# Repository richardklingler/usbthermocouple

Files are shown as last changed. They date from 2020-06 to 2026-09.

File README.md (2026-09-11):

# 2-channel USB thermocouple sensor

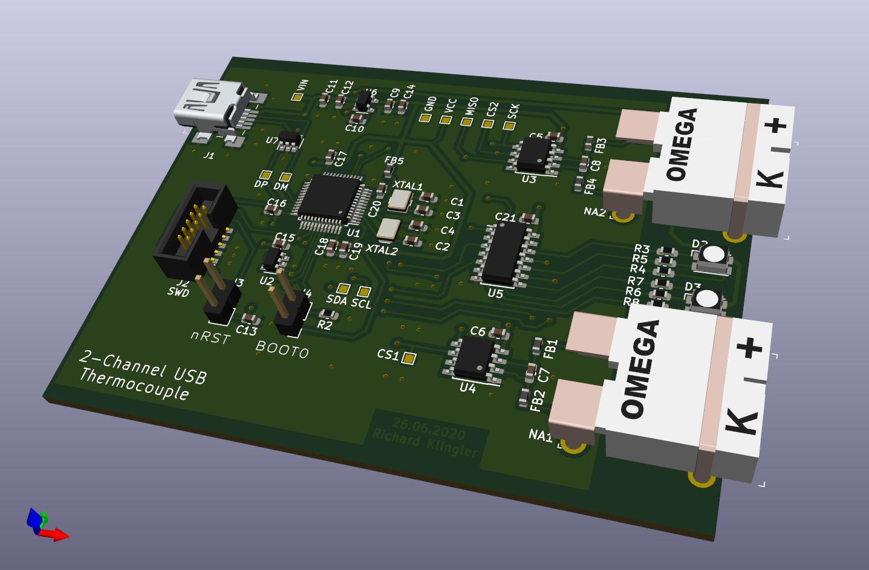
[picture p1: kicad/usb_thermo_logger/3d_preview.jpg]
USB Thermocouple Sensor


### Introduction

This is my first ever published project on Github, so most probably not error free (o;

It is a small 60mm x 80mm USB device which reads out temperatures from two K-type thermocouple sensors via MAX31855 converters.
As the main controller a STM32F070CBT6 was chosen due to the simplicity in setting up the STM32CubeIDE and configure it for USB CDC mode.

[**STM32CubeIDE**](https://www.st.com/en/development-tools/stm32cubeide.html)

For schematic and PCB design the great KiCAD software was used:

[**KiCAD**](https://www.kicad.org/)

### Repository layout

| Folder | Content |
|---|---|
| `kicad/usb_thermo_logger` | Schematic, PCB layout, 3D preview, datasheets |
| `openscad` | Front and back panels for the enclosure (`.scad` and `.stl`) |
| `stm32/USB_Thermologger_2` | Firmware, STM32CubeIDE project |
| `python` | PyQt5 logger application for the **previous** firmware (see below) |

### How it works

The device is powered from the USB port and registers as a USB CDC serial interface, so no driver is needed:

| OS | Device |
|---|---|
| Linux | `/dev/ttyACM0` |
| macOS | `/dev/cu.usbmodem…` |
| Windows | `COMx` |

The baud rate setting doesn't matter.

| USB descriptor | Value |
|---|---|
| Vendor ID / Product ID | `0x1209` / `0x5304` ([pid.codes](https://pid.codes/1209/5304/)) |
| Manufacturer | Klingler Engineering |
| Product | USB Thermocouple Logger |
| Serial number | Unique per device, derived from the STM32 chip ID |

The device doesn't send anything on its own. The host software asks for a measurement whenever it wants one, and adds its own timestamps.
This keeps the firmware simple: no clock to set, no drift, and the polling interval is completely up to the host.

The MAX31855 converts about 10 times per second, so polling faster than every 100 ms just returns the same value again.

### USB commands

| Command | Reply | Function |
|---|---|---|
| `?` | `24.50,23.75` | Read all channels |
| `*IDN?` | `Klingler Engineering,TC2,208438763130,1.0.0` | Identify the device |
| `C?` | `2` | Number of channels |
| `X1704` | none | Enter the DFU bootloader (see [Firmware update](#firmware-update)) |

Every reply is one line terminated by CR LF (`\r\n`).

Commands don't need a line ending, but **each command has to arrive in one piece**. The firmware looks at every USB packet on its own, so send the whole command with a single write.
A terminal program like `screen` sends every keystroke separately, which only works for the single-character `?`.

Send one command and wait for its reply before sending the next one.

### Identification

`*IDN?` follows the usual convention of measurement instruments and returns four comma-separated fields:

| Field | Example | Meaning |
|---|---|---|
| 1 | `Klingler Engineering` | Manufacturer |
| 2 | `TC2` | Model |
| 3 | `208438763130` | Serial number, identical to the USB serial number |
| 4 | `1.0.0` | Firmware version |

`C?` returns the number of thermocouple channels. Host software should use it instead of assuming a fixed number, so it also works with devices that have more channels.

### Reply format

After a `?`, the device replies with one line containing one value per channel, separated by commas. On the 2-channel device:

| Reply | Meaning |
|---|---|
| `24.50,23.75` | Both channels have a thermocouple |
| `24.50,-` | Only channel 1 has a valid reading |
| `-,23.75` | Only channel 2 has a valid reading |
| `-,-` | No valid reading on either channel |

Values are in degrees Celsius with a resolution of 0.25 °C. Negative temperatures are reported as negative values, e.g. `-12.25`.
The MAX31855 reports -270 °C to +1800 °C; the usable range of a K-type thermocouple itself is roughly -200 °C to +1350 °C.

### Errors

A `-` is sent for a channel when the MAX31855 reports a fault:

- thermocouple not connected (open circuit)
- thermocouple shorted to GND
- thermocouple shorted to VCC

### Quick test

With `screen` on Linux or macOS, type `?` and the reply appears (exit with Ctrl-A, then K):

```
screen /dev/ttyACM0 115200
```

For the other commands, use Python and [pyserial](https://pypi.org/project/pyserial/), which sends each command in one write:

```python
import serial

with serial.Serial('/dev/ttyACM0', timeout=1) as port:   # macOS: /dev/cu.usbmodem..., Windows: COM3
    for command in (b'*IDN?', b'C?', b'?'):
        port.write(command)
        print(command.decode(), '->', port.readline().decode().strip())
```

A simple logger that polls once per second and adds host timestamps:

```python
import serial, time
from datetime import datetime

with serial.Serial('/dev/ttyACM0', timeout=1) as port:
    while True:
        port.reset_input_buffer()
        port.write(b'?')
        reply = port.readline().decode(errors='replace').strip()
        print(f"{datetime.now().isoformat(timespec='milliseconds')},{reply}")
        time.sleep(1)
```

### Building the firmware

1. In STM32CubeIDE, use *File → Import → Existing Projects into Workspace* and select `stm32/USB_Thermologger_2`.
2. Build the *Release* configuration.
3. To get a `.bin` file for DFU flashing, enable *Project → Properties → C/C++ Build → Settings → MCU Post build outputs → Convert to binary file*.

### Firmware update

The device can be put into the STM32 DFU bootloader by sending a command, so no BOOT0 jumper or programmer is needed:

```
printf 'X1704' > /dev/ttyACM0
```

The device then re-enumerates as *STM32 BOOTLOADER* (`0483:df11`). Flash the new firmware with [dfu-util](https://dfu-util.sourceforge.net/), which is also available via Homebrew on macOS:

```
dfu-util -a 0 -s 0x08000000:leave -D stm32/USB_Thermologger_2/Release/USB_Thermologger_2.bin
```

Alternatively the firmware can be flashed directly from STM32CubeIDE with an ST-LINK via SWD.

### Changes

**September 2026**

- Project updated for current STM32CubeIDE versions and toolchains.
- The device no longer sends measurements continuously. It only replies to `?`.
- Removed the RTC time (`T`), date (`D`) and interval (`I`) commands, and the planned offset command (`O`). Timestamps, interval and calibration offsets are now the job of the host software.
- New commands `*IDN?` (identification) and `C?` (channel count).
- The device now uses its own USB ID `1209:5304` and reports as *USB Thermocouple Logger* by *Klingler Engineering*, instead of ST's generic `0483:5740`.
- Sensor faults are detected via the MAX31855 fault bit.
- Fixed negative temperatures, which were previously reported as values above 2000 °C.
- Reply lines now end with `\r\n` instead of `\n\r`.

The PyQt5 application in `python/` was written for the previous firmware (continuous output, RTC commands) and doesn't work with the current firmware.

### License

Firmware and software: GPL-3.0, see [LICENSE](LICENSE).
Hardware: CERN Open Hardware Licence v1.2, see [OSH_License.txt](OSH_License.txt).

### Donations

All my projects (currently not much but growing ;o) are self financed. If you like you can make a donation to my Paypal.me link:

paypal.me/renderingfun
[**Paypal Me Link**](https://paypal.me/renderingfun)

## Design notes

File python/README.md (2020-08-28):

### Sample Python Qt5 USB Thermo logger application

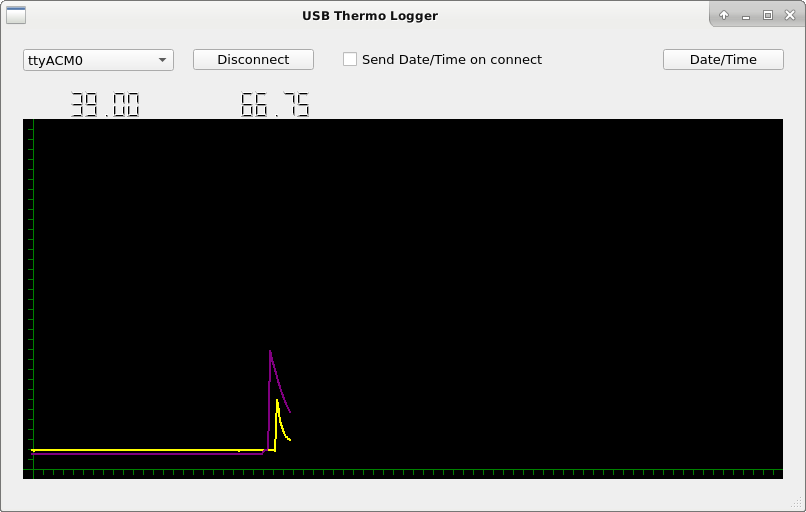
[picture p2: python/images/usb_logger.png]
PyQt5 USB logger


This is a simple PyQt5 application for rendering the returned temperature data from my USB thermocouple converter.

The main window layout is done in Qt 5 designer and can be converted to the modules/MainWindow.py file with:

    pyuic5 designer/main.ui -o modules/MainWindow.py

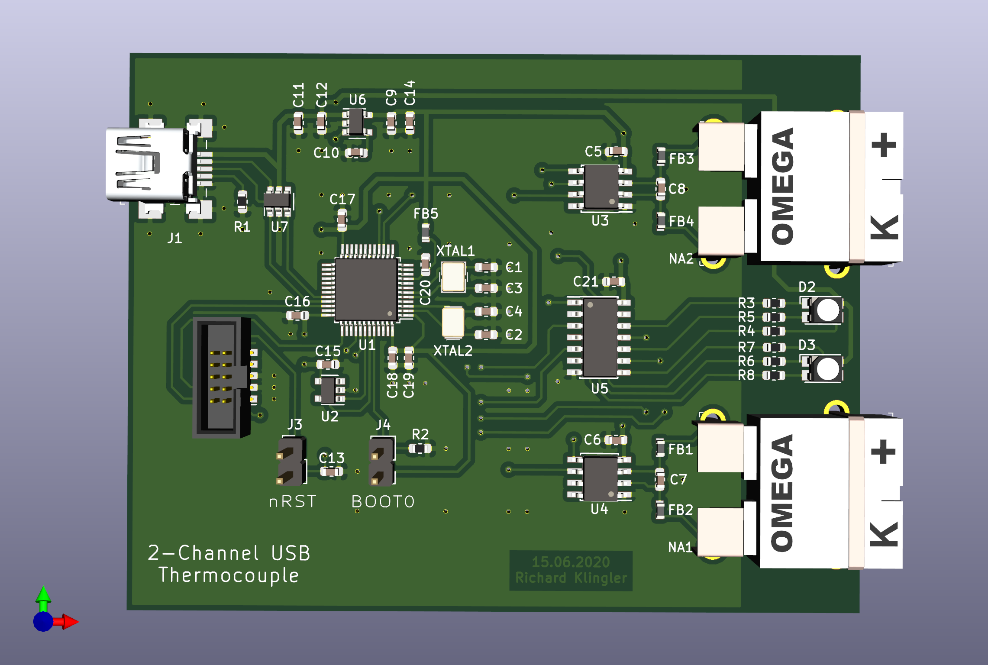
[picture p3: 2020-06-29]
kicad/usb_thermo_logger/3d_preview.png

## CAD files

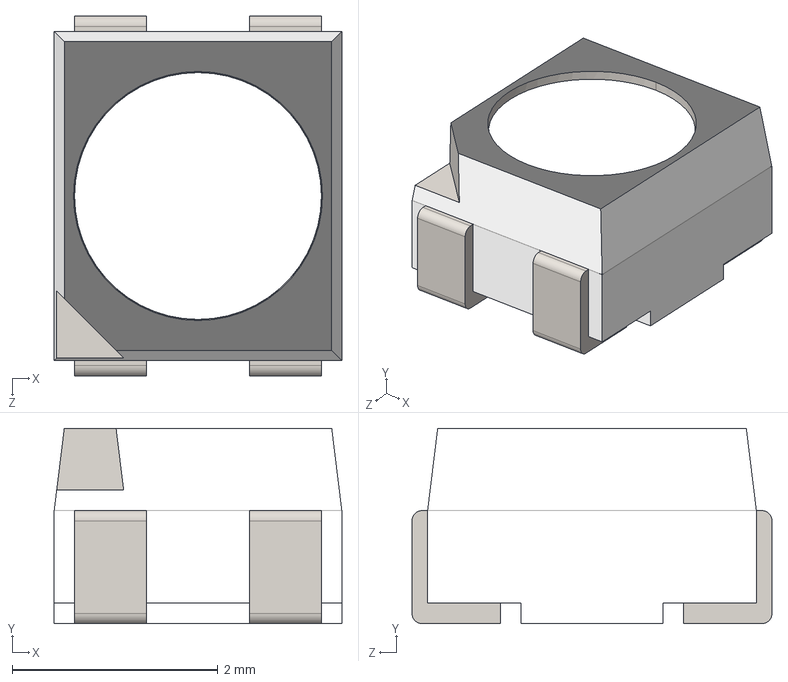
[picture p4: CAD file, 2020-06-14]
kicad/usb_thermo_logger/3d/ASMB-MTB0-0A3A2.STEP
2.80 x 1.90 x 3.50 mm

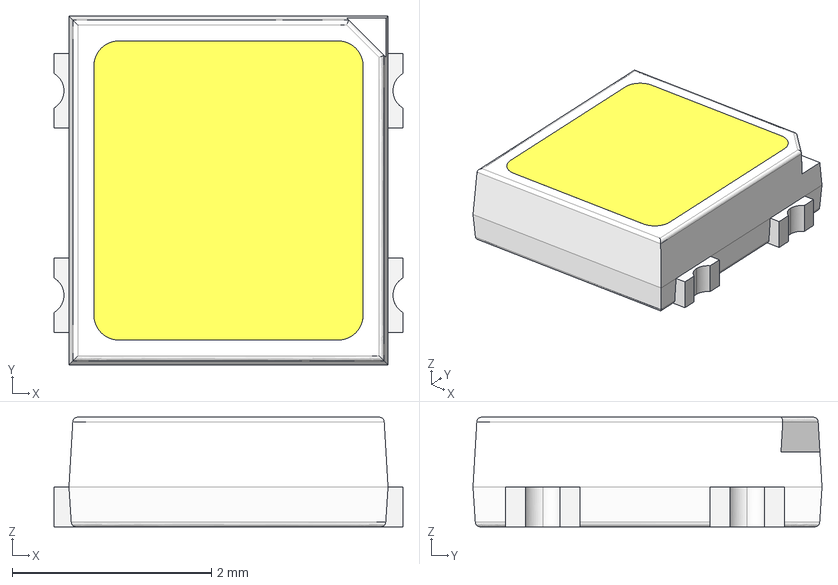
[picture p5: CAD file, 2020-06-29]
kicad/usb_thermo_logger/3d/PLCC4.stp
3.50 x 3.50 x 1.10 mm

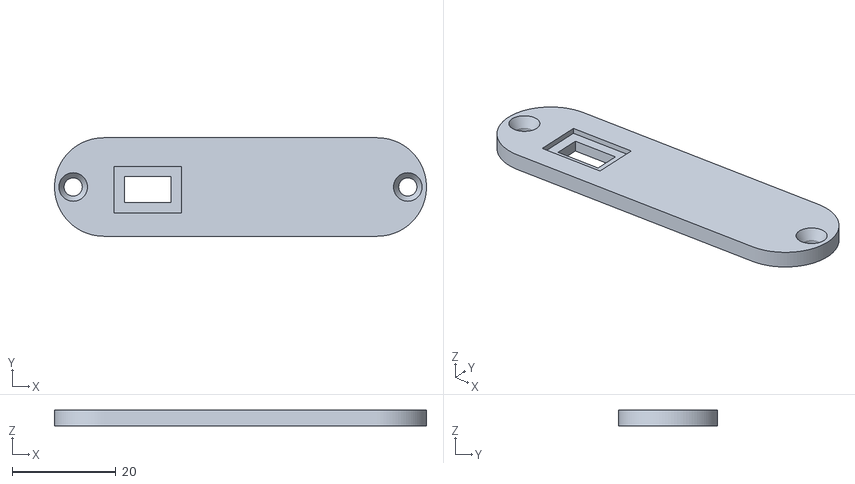
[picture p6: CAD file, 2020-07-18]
openscad/panel_back.stl
71.7 x 19.0 x 3.00

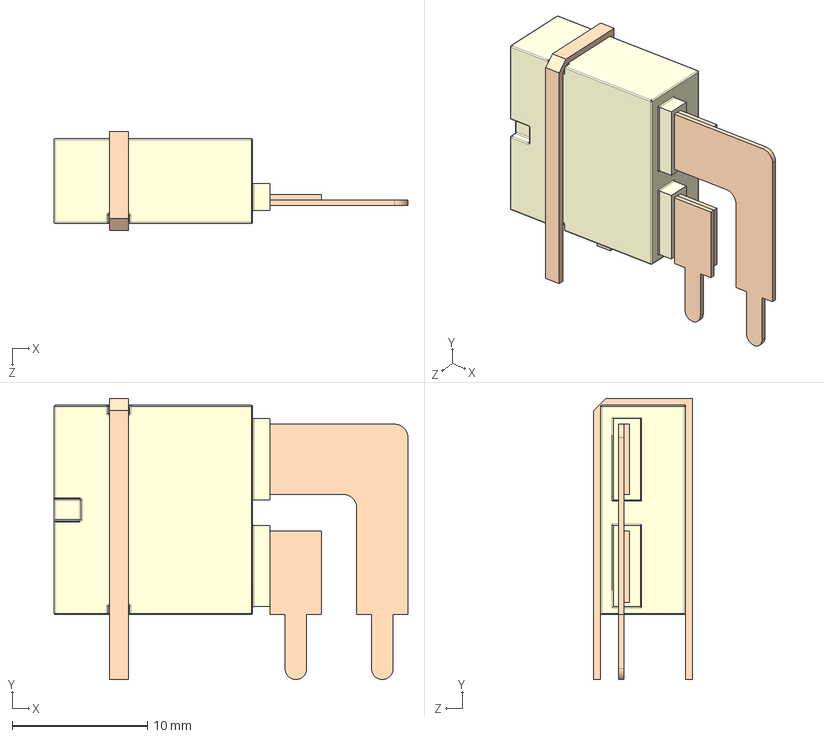
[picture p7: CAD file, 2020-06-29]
kicad/usb_thermo_logger/3d/PCC-SMP-V-K--3DModel-STEP-56544.STEP
26.2 x 20.8 x 7.30 mm

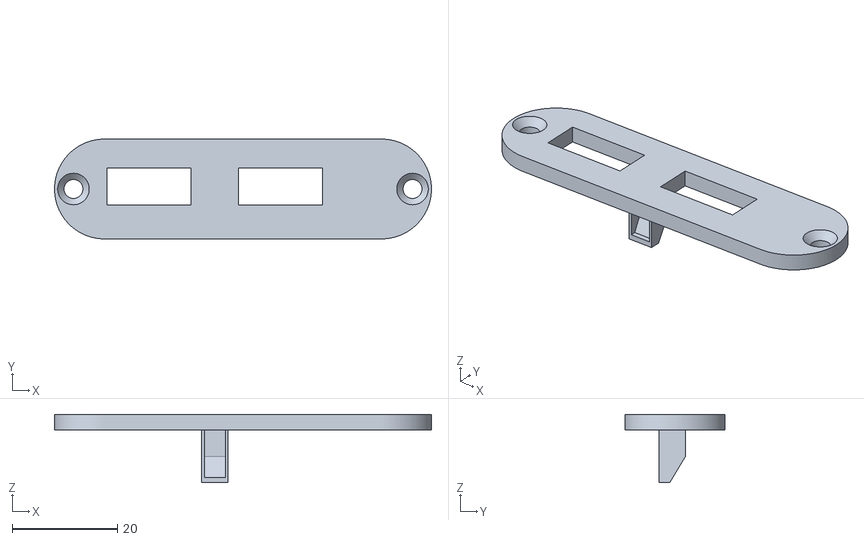
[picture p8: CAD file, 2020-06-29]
openscad/panel_front.stl
71.7 x 19.0 x 13.0

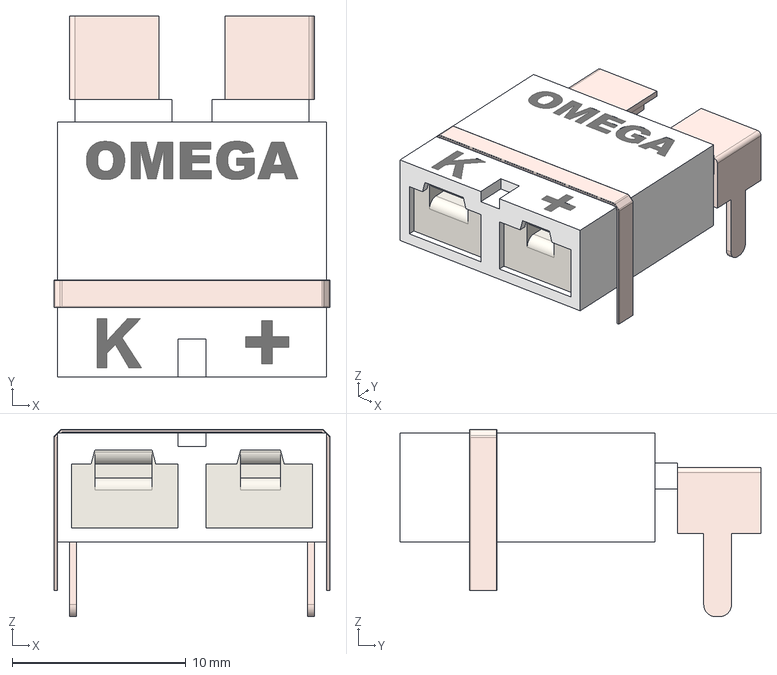
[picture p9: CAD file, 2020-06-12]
kicad/usb_thermo_logger/3d/PCC-SMP-K.step
15.9 x 20.8 x 10.8 mm

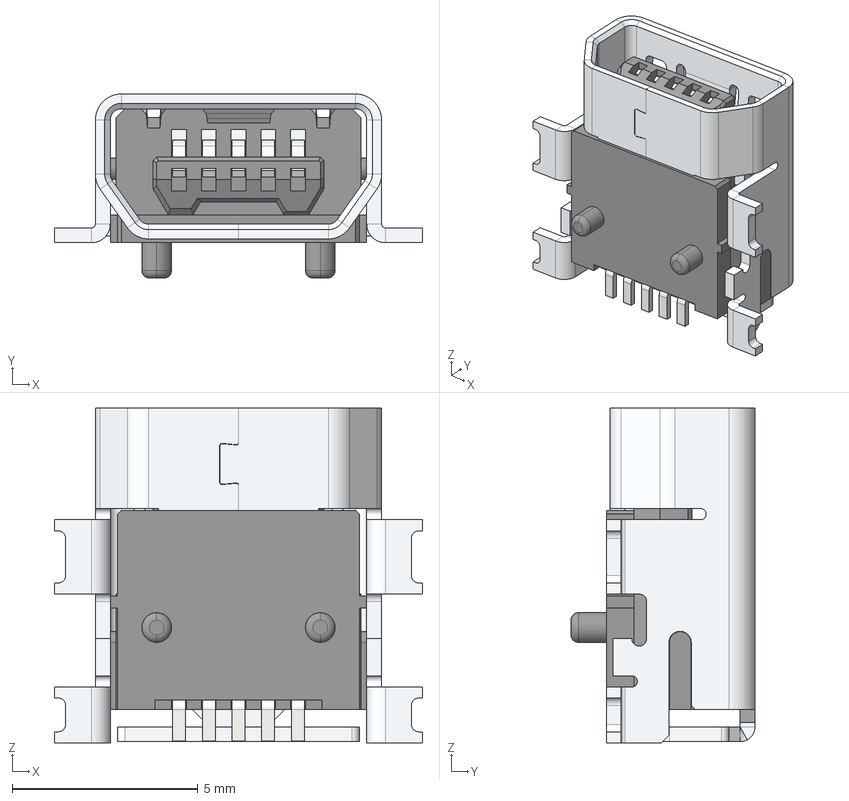
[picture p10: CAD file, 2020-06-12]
kicad/usb_thermo_logger/3d/MOLEX_0678038020.step
9.90 x 4.95 x 9.00 mm

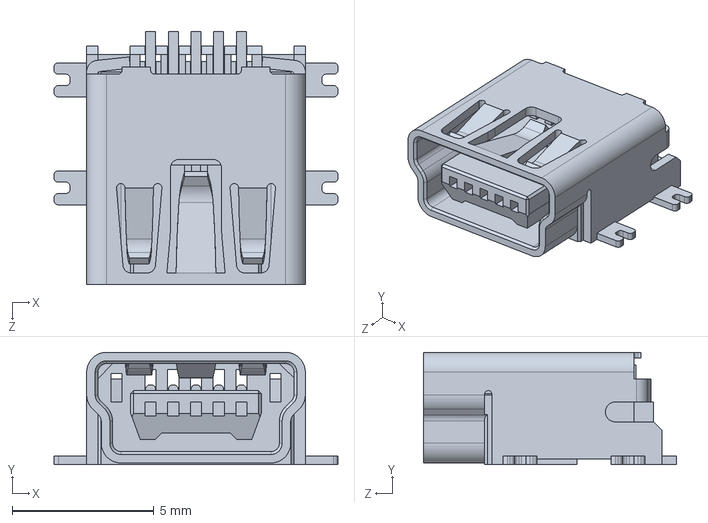
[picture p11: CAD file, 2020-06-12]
kicad/usb_thermo_logger/3d/USB_Mini_B_SMD_buchse.step
10.0 x 3.96 x 8.90 mm

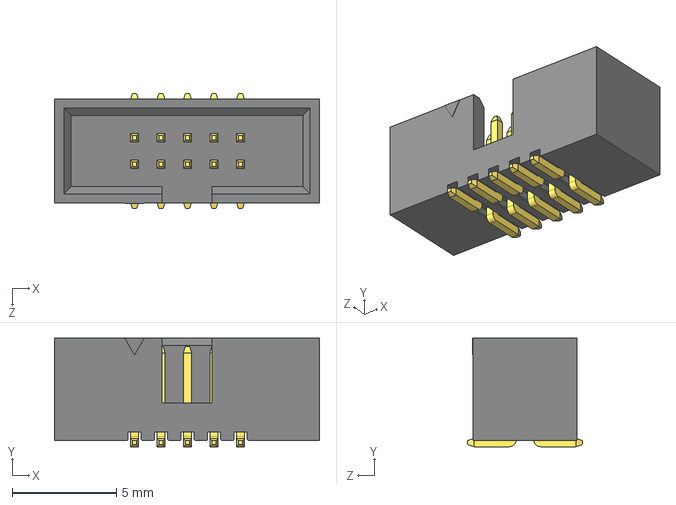
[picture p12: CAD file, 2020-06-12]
kicad/usb_thermo_logger/3d/3220-10-0300-00 3D.step
12.7 x 5.20 x 5.50 mm
801-2195SM-10
802-2195SM x 10

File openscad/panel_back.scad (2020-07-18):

$fn = 100;

// Edge radius of the hammond 1455B802 case
$r = 9.5;

// Width
$w = 71.74;

// Thickness
$t = 3;

// Distance of screw holes
$d = 64.53;
// Screw radius
$sr = 3.5 / 2;

// Height of PCB top
$ph = 6.5;
// K connector dimension (w x h
$cw = 9;
$ch = 5;

difference()
{
    union()
    {
        // Whole front element
        hull()
        {
            translate([$r, $r, 0]) cylinder($t, $r, $r);
            translate([$w - $r, $r, 0]) cylinder($t, $r, $r);
        }
    }
    // Screw holes
    translate([($w / 2) - ($d / 2), $r, -1]) cylinder($t + 2, $sr, $sr);
    translate([($w / 2) + ($d / 2), $r, -1]) cylinder($t + 2, $sr, $sr);
    translate([($w / 2) - ($d / 2), $r, $t - 2]) cylinder(2.1, $sr, 2.8);
    translate([($w / 2) + ($d / 2), $r, $t - 2]) cylinder(2.1, $sr, 2.8);

    // Connector cutouts
    translate([13.5, $ph, -1]) cube([$cw, $ch, $t + 2], false);
    translate([13.5 - 2, $ph - 2, 2]) cube([$cw + 4, $ch + 4, $t + 2], false);
}

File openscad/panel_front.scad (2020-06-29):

$fn = 100;

// Edge radius of the hammond 1455B802 case
$r = 9.5;

// Width
$w = 71.74;

// Thickness
$t = 3;

// Distance of screw holes
$d = 64.53;
// Screw radius
$sr = 3.6 / 2;

// Height of PCB top
$ph = 6.5;
// K connector dimension (w x h
$cw = 16;
$ch = 7;

difference()
{
    union()
    {
        // Whole front element
        hull()
        {
            translate([$r, $r, 0]) cylinder($t, $r, $r);
            translate([$w - $r, $r, 0]) cylinder($t, $r, $r);
        }
        // LED
        hull()
        {
            translate([28, $ph, -5]) cube([5, 5, 5], false);
            translate([28, $ph, -10]) cube([5, 2, 5], false);
        }
    }
//    translate([28.5, $ph - 1, -8]) cube([4, 4, 10], false);
    hull()
    {
        translate([28.5, $ph - 1, -5]) cube([4, 4, 5], false);
        translate([28.5, $ph - 1, -9]) cube([4, 2, 5], false);
    }
    
    // Screw holes
    translate([($w / 2) - ($d / 2), $r, -1]) cylinder($t + 2, $sr, $sr);
    translate([($w / 2) + ($d / 2), $r, -1]) cylinder($t + 2, $sr, $sr);
    translate([($w / 2) - ($d / 2), $r, $t - 1.5]) cylinder($t + 2, $sr, $sr + 4);
    translate([($w / 2) + ($d / 2), $r, $t -1.5]) cylinder($t + 2, $sr, $sr + 4);

    // Connector cutouts
    translate([10, $ph, -1]) cube([$cw, $ch, $t + 2], false);
    translate([35, $ph, -1]) cube([$cw, $ch, $t + 2], false);
}

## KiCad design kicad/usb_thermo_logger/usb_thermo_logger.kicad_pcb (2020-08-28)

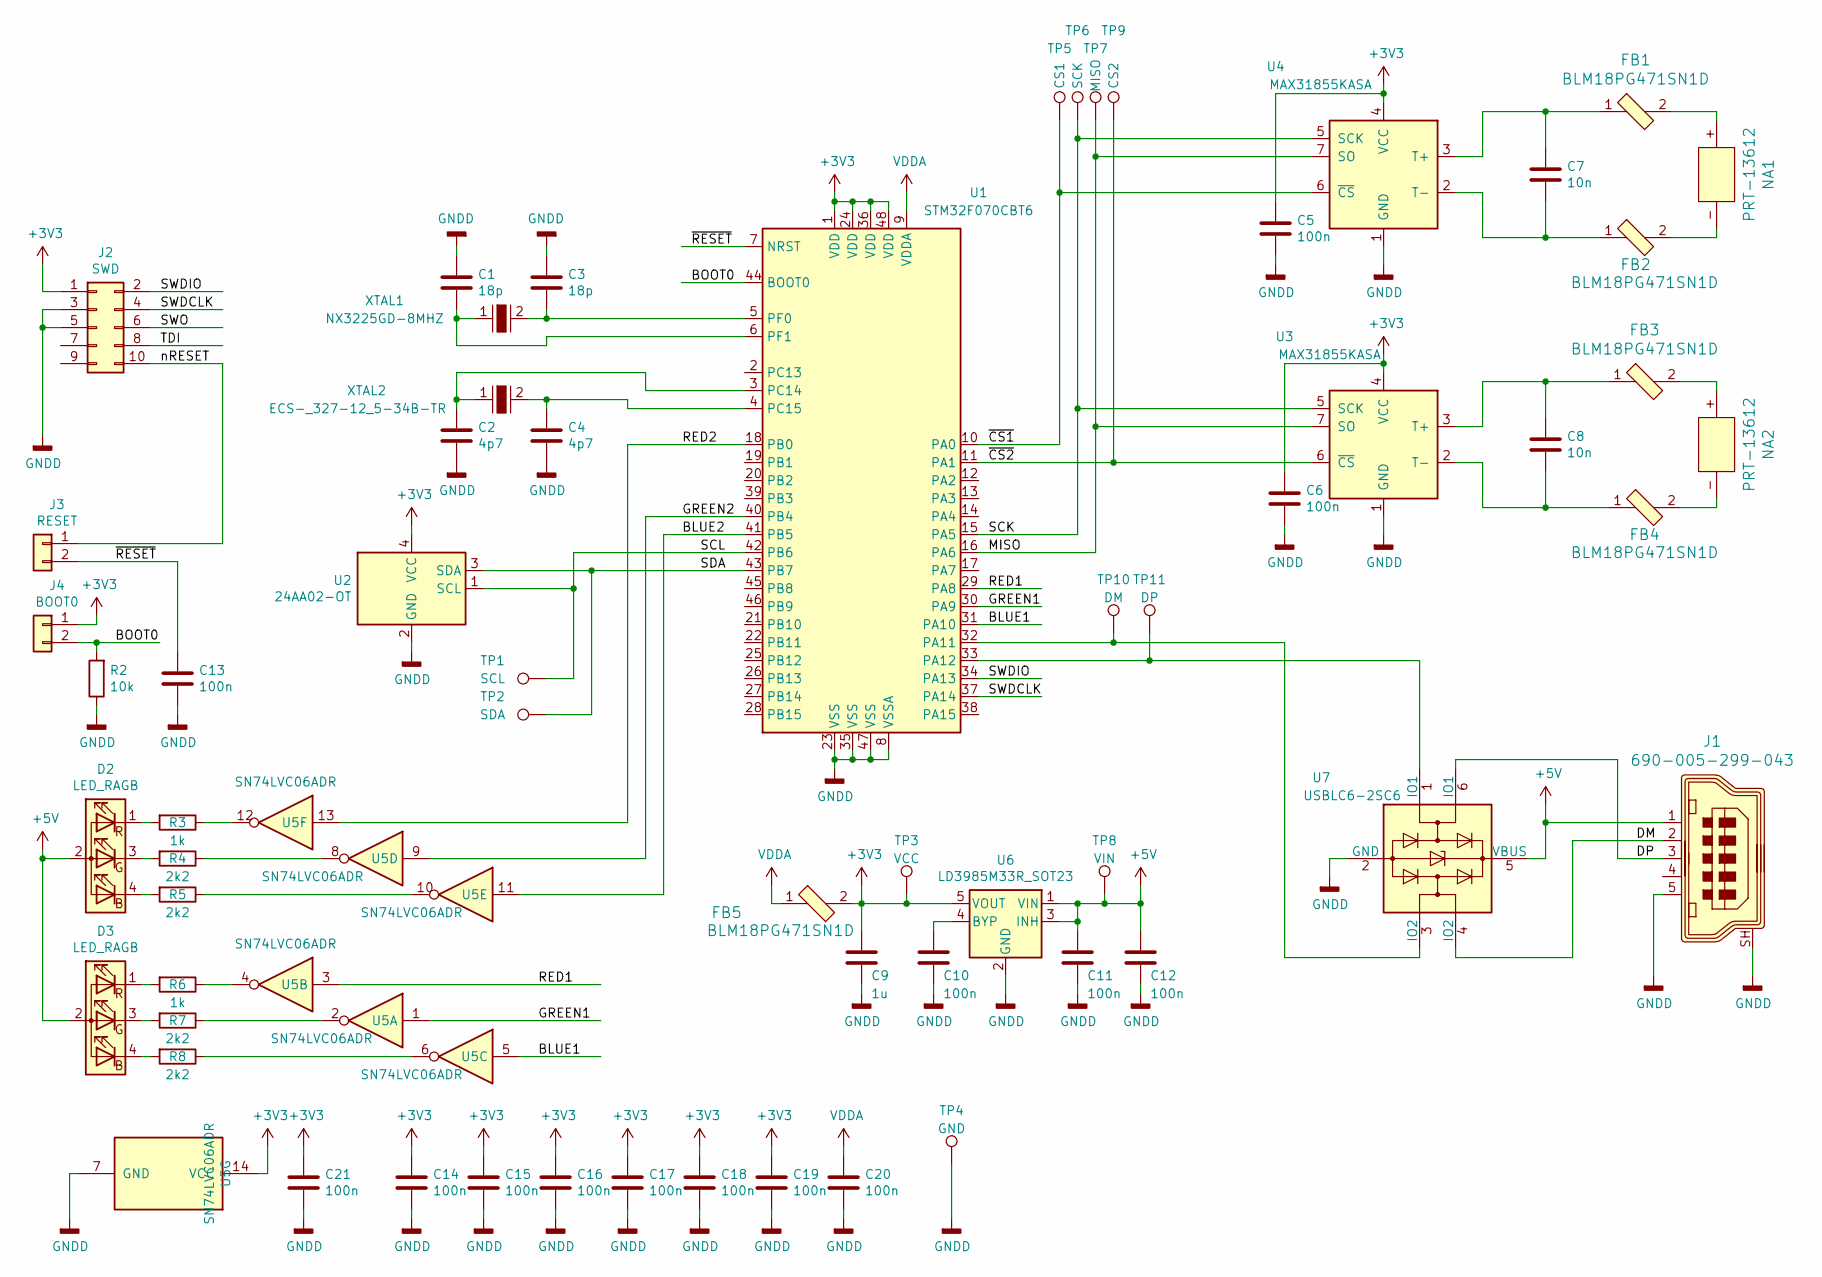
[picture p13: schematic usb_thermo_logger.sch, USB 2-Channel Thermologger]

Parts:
C1, C3: 18p; C_0603_1608Metric
C2, C4: 4p7; C_0603_1608Metric
C5, C6, C10, C11, C12, C13, C14, C15, C16, C17, C18, C19, C20, C21: 100n; C_0603_1608Metric
C7, C8: 10n; C_0603_1608Metric
C9: 1u; C_0603_1608Metric
D2, D3: LED_RAGB; LED_Avago_PLCC4_3.2x2.8mm_CW
FB1, FB2, FB3, FB4, FB5: BLM18PG471SN1D; 0603; MPN BLM18PG471SN1D; Digi-Key_PN 490-5223-1-ND
J1: 690-005-299-043; USB_Mini_B_Female_690-005-299-043; MPN 690-005-299-043; Digi-Key_PN 151-1206-1-ND
J2: SWD; PinHeader_2x05_P1.27mm_Vertical_SMD
J3: RESET; PinHeader_1x02_P2.54mm_Vertical
J4: BOOT0; PinHeader_1x02_P2.54mm_Vertical
NA1, NA2: PRT-13612; Thermocouple_Connector_PCC-SMP-K; MPN PRT-13612; Digi-Key_PN 1568-1306-ND
R2: 10k; R_0603_1608Metric
R3, R6: 1k; R_0603_1608Metric
R4, R5, R7, R8: 2k2; R_0603_1608Metric
TP1: SCL; TestPoint_Pad_1.0x1.0mm
TP2: SDA; TestPoint_Pad_1.0x1.0mm
TP3: VCC; TestPoint_Pad_1.0x1.0mm
TP4: GND; TestPoint_Pad_1.0x1.0mm
TP5: CS1; TestPoint_Pad_1.0x1.0mm
TP6: SCK; TestPoint_Pad_1.0x1.0mm
TP7: MISO; TestPoint_Pad_1.0x1.0mm
TP8: VIN; TestPoint_Pad_1.0x1.0mm
TP9: CS2; TestPoint_Pad_1.0x1.0mm
TP10: DM; TestPoint_Pad_1.0x1.0mm
TP11: DP; TestPoint_Pad_1.0x1.0mm
U1: STM32F070CBT6; LQFP-48_7x7mm_P0.5mm
U2: 24AA02-OT; SOT-23-5
U3, U4: MAX31855KASA; SOIC-8_3.9x4.9mm_P1.27mm
U5: SN74LVC06ADR; SOIC-14_3.9x8.7mm_P1.27mm; Digikey 296-14905-1-ND
U6: LD3985M33R_SOT23; SOT-23-5
U7: USBLC6-2SC6; SOT-23-6
XTAL1: NX3225GD-8MHZ; SMD-2_3.2x2.5mm; MPN NX3225GD-8MHZ-STD-CRA-3; Digi-Key_PN 644-1178-1-ND
XTAL2: ECS-_327-12_5-34B-TR; SMD-2_3.2x1.5mm; MPN ECS-.327-12.5-34B-TR; Digi-Key_PN XC1617CT-ND

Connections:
+3V3: C5.1, C6.1, C9.1, C14.1, C15.1, C16.1, C17.1, C18.1, C19.1, C21.1, FB5.2, J2.1, J4.1, TP3.1, U1.1 (VDD), U1.24 (VDD), U1.36 (VDD), U1.48 (VDD), U2.4 (VCC), U3.4 (VCC), U4.4 (VCC), U5.14 (VCC), U6.5 (VOUT)
+5V: C11.1, C12.1, D2.2 (A), D3.2 (A), J1.1, TP8.1, U6.1 (VIN), U6.3 (INH), U7.5 (VBUS)
/BLUE1: U1.31 (PA10), U5.5
/BLUE2: U1.41 (PB5), U5.11
/BOOT0: J4.2, R2.2, U1.44 (BOOT0)
/DM: J1.2, U7.4 (IO2)
/DP: J1.3, U7.6 (IO1)
/GREEN1: U1.30 (PA9), U5.1
/GREEN2: U1.40 (PB4), U5.9
/MISO: TP7.1, U1.16 (PA6), U3.7 (SO), U4.7 (SO)
/RED1: U1.29 (PA8), U5.3
/RED2: U1.18 (PB0), U5.13
/SCK: TP6.1, U1.15 (PA5), U3.5 (SCK), U4.5 (SCK)
/SCL: TP1.1, U1.42 (PB6), U2.1 (SCL)
/SDA: TP2.1, U1.43 (PB7), U2.3 (SDA)
/SWDCLK: J2.4, U1.37 (PA14)
/SWDIO: J2.2, U1.34 (PA13)
/SWO: J2.6
/TDI: J2.8
/nRESET: J2.10, J3.1
/~CS1: TP5.1, U1.10 (PA0), U4.6 (~CS~)
/~CS2: TP9.1, U1.11 (PA1), U3.6 (~CS~)
/~RESET: C13.1, J3.2, U1.7 (NRST)
GNDD: C1.1, C2.2, C3.1, C4.2, C5.2, C6.2, C9.2, C10.2, C11.2, C12.2, C13.2, C14.2, C15.2, C16.2, C17.2, C18.2, C19.2, C20.2, C21.2, J1.5, J1.SH, J2.3, J2.5, R2.1, TP4.1, U1.8 (VSSA), U1.23 (VSS), U1.35 (VSS), U1.47 (VSS), U2.2 (GND), U3.1 (GND), U4.1 (GND), U5.7 (GND), U6.2 (GND), U7.2 (GND)
unnamed: C1.2, U1.6 (PF1), XTAL1.1
unnamed: C2.1, U1.3 (PC14), XTAL2.1
unnamed: C3.2, U1.5 (PF0), XTAL1.2
unnamed: C4.1, U1.4 (PC15), XTAL2.2
unnamed: C7.1, FB1.1, U4.3 (T+)
unnamed: C7.2, FB2.1, U4.2 (T-)
unnamed: C8.1, FB3.1, U3.3 (T+)
unnamed: C8.2, FB4.1, U3.2 (T-)
unnamed: C10.1, U6.4 (BYP)
unnamed: D2.1 (RK), R3.2
unnamed: D2.3 (GK), R4.2
unnamed: D2.4 (BK), R5.2
unnamed: D3.1 (RK), R6.2
unnamed: D3.3 (GK), R7.2
unnamed: D3.4 (BK), R8.2
unnamed: FB1.2, NA1.+
unnamed: FB2.2, NA1.-
unnamed: FB3.2, NA2.+
unnamed: FB4.2, NA2.-
unnamed: R3.1, U5.12
unnamed: R4.1, U5.8
unnamed: R5.1, U5.10
unnamed: R6.1, U5.4
unnamed: R7.1, U5.2
unnamed: R8.1, U5.6
unnamed: TP10.1, U1.32 (PA11), U7.3 (IO2)
unnamed: TP11.1, U1.33 (PA12), U7.1 (IO1)
VDDA: C20.1, FB5.1, U1.9 (VDDA)

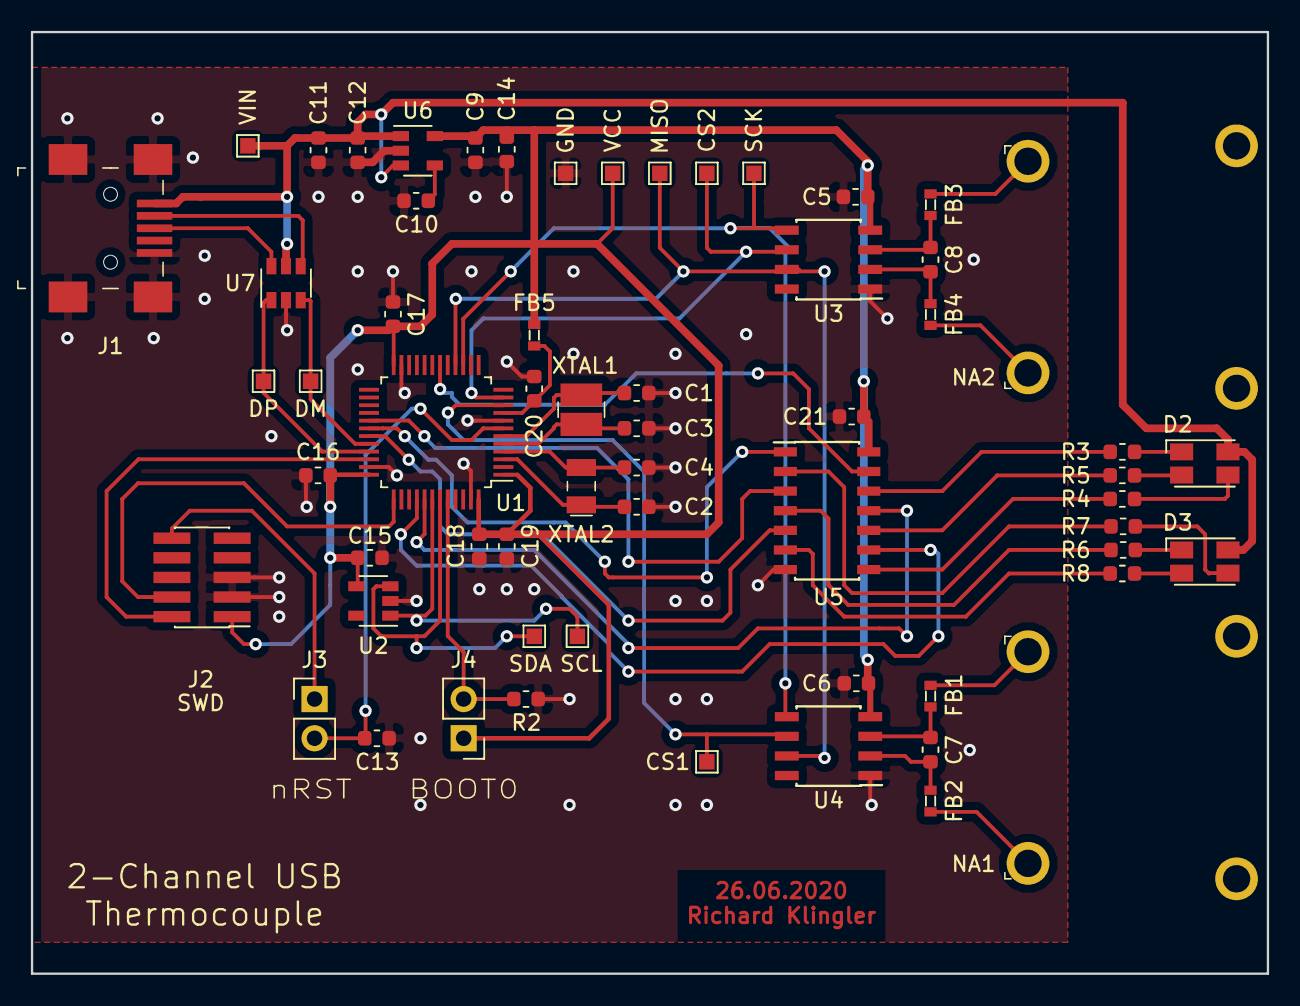
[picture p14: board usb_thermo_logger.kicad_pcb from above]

Board: 2 copper layers, 80.0 x 61.0 mm, 61 parts (0 on the bottom side), 50 nets.

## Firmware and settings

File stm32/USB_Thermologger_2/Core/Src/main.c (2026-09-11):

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

/* Includes ------------------------------------------------------------------*/
#include "main.h"
#include "usb_device.h"

/* USER CODE BEGIN Includes */
#include "usbd_cdc_if.h"

/* USER CODE END Includes */

/* USER CODE BEGIN PD */
#define FW_MANUFACTURER  "Klingler Engineering"
#define FW_MODEL         "TC2"
#define FW_VERSION       "1.0.0"
#define NUM_CHANNELS     2
/* USER CODE END PD */

ADC_HandleTypeDef hadc;

I2C_HandleTypeDef hi2c1;

RTC_HandleTypeDef hrtc;

SPI_HandleTypeDef hspi1;

/* USER CODE BEGIN PV */
uint8_t switchToBootloader __attribute__ ((section (".noinit")));
volatile uint8_t send_usb = 0;
volatile uint32_t interval = 1, int_reload = 1;
uint8_t send_idn = 0;
uint8_t send_channels = 0;
char serial_number[13];
extern USBD_HandleTypeDef hUsbDeviceFS;
static const uint16_t tc_cs_pins[NUM_CHANNELS] = { MAX1_Pin, MAX2_Pin };
/* USER CODE END PV */

void SystemClock_Config(void);
static void MX_GPIO_Init(void);
static void MX_ADC_Init(void);
static void MX_I2C1_Init(void);
static void MX_RTC_Init(void);
static void MX_SPI1_Init(void);
/* USER CODE BEGIN PFP */
static int USB_TxIdle(void);
void USB_TriggerBootloader(void);
void USB_BootloaderInit(void);
static int MAX31855_Read(uint16_t pin, double *temp);/* USER CODE END PFP */
/* USER CODE END PFP */

/**
  * @brief  The application entry point.
  * @retval int
  */
int main(void)
{
  /* USER CODE BEGIN 1 */
  if(switchToBootloader == 0x11)
	  USB_BootloaderInit();

  /* USER CODE END 1 */

  /* MCU Configuration--------------------------------------------------------*/

  /* Reset of all peripherals, Initializes the Flash interface and the Systick. */
  HAL_Init();

  /* Configure the system clock */
  SystemClock_Config();

  /* Initialize all configured peripherals */
  MX_GPIO_Init();
  MX_ADC_Init();
  MX_I2C1_Init();
  MX_RTC_Init();
  MX_SPI1_Init();
  MX_USB_DEVICE_Init();
  /* USER CODE BEGIN 2 */

  uint32_t length = 0;

  HAL_GPIO_WritePin(GPIOA, MAX1_Pin, 1);
  HAL_GPIO_WritePin(GPIOA, MAX2_Pin, 1);

  char buffer[96];
  uint8_t usbrx[64];

  uint32_t id1 = *(uint32_t *)UID_BASE;
  uint32_t id2 = *(uint32_t *)(UID_BASE + 4);
  uint32_t id3 = *(uint32_t *)(UID_BASE + 8);
  snprintf(serial_number, sizeof serial_number, "%08lX%04lX", id1 + id3, id2 >> 16);

  /* USER CODE END 2 */

  /* Infinite loop */
  /* USER CODE BEGIN WHILE */
  while (1)
  {
    /* USER CODE END WHILE */

    /* USER CODE BEGIN 3 */

	  if (USB_TxIdle())
	  {
	  	if (send_idn)
	  	{
	  		int n = snprintf(buffer, sizeof buffer, "%s,%s,%s,%s\r\n",
	  		                 FW_MANUFACTURER, FW_MODEL, serial_number, FW_VERSION);
	  		CDC_Transmit_FS((uint8_t *)buffer, n);
	  		send_idn = 0;
	  	}
	  	else if (send_channels)
	  	{
	  		int n = snprintf(buffer, sizeof buffer, "%d\r\n", NUM_CHANNELS);
	  		CDC_Transmit_FS((uint8_t *)buffer, n);
	  		send_channels = 0;
	  	}
	  	else if (send_usb)
	  	{
	  		int n = 0;
	  		for (int ch = 0; ch < NUM_CHANNELS; ch++)
	  		{
	  			double t;
	  			if (ch > 0)
	  				n += snprintf(buffer + n, sizeof buffer - n, ",");
	  			if (MAX31855_Read(tc_cs_pins[ch], &t))
	  				n += snprintf(buffer + n, sizeof buffer - n, "%.2f", t);
	  			else
	  				n += snprintf(buffer + n, sizeof buffer - n, "-");
	  		}
	  		n += snprintf(buffer + n, sizeof buffer - n, "\r\n");
	  		CDC_Transmit_FS((uint8_t *)buffer, n);
	  		send_usb = 0;
	  	}
	  }

	  if (VCP_retrieveInputData(usbrx,&length)!=0)
  	  {
		  if((length >= 1) && (usbrx[0] != 0))
		  {
			  switch (usbrx[0])
			  {
			  	case 'X':
			  		if ((usbrx[1] == '1') && (usbrx[2] == '7') && (usbrx[3] == '0') && (usbrx[4] == '4'))
			  			USB_TriggerBootloader();
			  		break;

			  	case '?':
			  		send_usb = 1;
			  		break;

			  	case '*':
			  		if ((length >= 5) && (strncmp(usbrx, "*IDN?", 5) == 0))
			  			send_idn = 1;
			  		break;

			  	case 'C':
			  		if ((length >= 2) && (usbrx[1] == '?'))
			  			send_channels = 1;
			  		break;
			  }
		  }
  	  }
  }
  /* USER CODE END 3 */
}

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
/* USER CODE BEGIN 4 */
static int USB_TxIdle(void)
{
	USBD_CDC_HandleTypeDef *hcdc = (USBD_CDC_HandleTypeDef *)hUsbDeviceFS.pClassData;
	return (hcdc != NULL) && (hcdc->TxState == 0);
}

static int MAX31855_Read(uint16_t pin, double *temp)
{
	uint8_t d[4];
	HAL_GPIO_WritePin(GPIOA, pin, GPIO_PIN_RESET);
	HAL_StatusTypeDef st = HAL_SPI_Receive(&hspi1, d, 4, 100);
	HAL_GPIO_WritePin(GPIOA, pin, GPIO_PIN_SET);

	if (st != HAL_OK || (d[1] & 0x01))	/* bit 16: fault (open, short GND/VCC) */
		return 0;

	int16_t raw = (int16_t)((d[0] << 8) | d[1]) >> 2;	/* 14-bit signed, 0.25 °C/LSB */
	*temp = raw * 0.25;
	return 1;
}

void HAL_RTC_AlarmAEventCallback(RTC_HandleTypeDef *hrtc)
{
/*
	interval--;
	if(interval == 0)
	{
		interval = int_reload;
		send_usb = 1;
	}
*/
}

void (*SysMemBootJump) (void);

void USB_BootloaderInit()
{
	switchToBootloader = 0x00;	//Reset the variable to prevent being stuck in the bootloader (since a device reset wont change it)
	volatile uint32_t addr = 0x1FFFC800;	//The STM32F070RB system memory start address
	SysMemBootJump = (void (*)(void)) (*((uint32_t *)(addr + 4)));	//Point the PC to the System Memory reset vector

	HAL_RCC_DeInit();		//Reset the system clock
	SysTick->CTRL = 0;		//Reset the  SysTick Timer
	SysTick->LOAD = 0;
	SysTick->VAL  = 0;

	__set_MSP(*(uint32_t *)addr);	//Set the Main Stack Pointer

	SysMemBootJump();				//Run our virtual function defined above that sets the PC

	while(1);
}

void USB_TriggerBootloader()
{
	switchToBootloader = 0x11;			//Set the noinit variable to be read by startup code
	NVIC_SystemReset();					//Reset the system
}

/* USER CODE END 4 */
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


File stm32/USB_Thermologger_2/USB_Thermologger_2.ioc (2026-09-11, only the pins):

Mcu.UserName=STM32F070CBTx
PA0.GPIO_Label=MAX1
PA0.Signal=GPIO_Output
PA1.GPIO_Label=MAX2
PA1.Signal=GPIO_Output
PA11.Signal=USB_DM
PA12.Signal=USB_DP
PA13.Signal=SYS_SWDIO
PA14.Signal=SYS_SWCLK
PA5.Signal=SPI1_SCK
PA6.Signal=SPI1_MISO
PB6.Signal=I2C1_SCL
PB7.Signal=I2C1_SDA
PC14-OSC32_IN.Signal=RCC_OSC32_IN
PC15-OSC32_OUT.Signal=RCC_OSC32_OUT
PF0-OSC_IN.Signal=RCC_OSC_IN
PF1-OSC_OUT.Signal=RCC_OSC_OUT

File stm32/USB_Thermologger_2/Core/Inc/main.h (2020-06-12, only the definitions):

#define MAX1_Pin GPIO_PIN_0
#define MAX1_GPIO_Port GPIOA
#define MAX2_Pin GPIO_PIN_1
#define MAX2_GPIO_Port GPIOA

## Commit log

2020-06-12 Added KiCAD design
    [3220-10-0300-00 3D.step, MOLEX_0678038020.step, PCC-SMP-K.step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]
2020-06-12 Added STM32CubeIDE project
2020-06-14 LED display changes, added OpenSCAD
    [ASMB-MTB0-0A3A2.STEP, panel_front.scad, panel_front.stl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]
2020-06-29 Layout changes
    [PCC-SMP-V-K--3DModel-STEP-56544.STEP, PLCC4.stp, panel_front.scad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]
2020-07-18 Added back panel openscad design
    [panel_back.scad, panel_back.stl]
2020-08-28 Added PyQt5 sample application for logging data
    [usb_thermo_logger.kicad_pcb]
2026-09-11 Update for newer STM32CubeIDE amd use host side read trigger with ?

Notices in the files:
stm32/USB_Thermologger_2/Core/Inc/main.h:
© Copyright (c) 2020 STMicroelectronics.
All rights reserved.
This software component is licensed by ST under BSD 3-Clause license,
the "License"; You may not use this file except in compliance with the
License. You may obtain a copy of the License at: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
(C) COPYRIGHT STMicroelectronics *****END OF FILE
